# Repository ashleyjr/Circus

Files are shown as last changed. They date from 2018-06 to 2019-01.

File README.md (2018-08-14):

# Circus

## Installs

### Python 2.7
#### pip           
$ sudo apt-get install python-pip python-dev build-essential      

$ sudo pip install --upgrade pip 

$ sudo pip install --upgrade virtualenv 

$ sudo apt-get install python-tk    

### matplotlib     
$ sudo pip install matplotlib

### 8051
SDCC

SimplicityStudio

### Schematic capture/layout
#### KiCad
$sudo add-apt-repository --yes ppa:js-reynaud/kicad-4

$sudo apt update

$sudo apt install kicad

### Docs
$ sudo apt-get install texlive-latex-base

$ sudo apt-get install texlive-latex-extra

### GUI
$ sudo apt-get install libgtk-3-dev

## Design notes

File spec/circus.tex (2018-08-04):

\documentclass[a4paper]{article}

\usepackage{fullpage} % Package to use full page
\usepackage{parskip} % Package to tweak paragraph skipping
\usepackage{tikz} % Package for drawing
\usepackage{amsmath}
\usepackage{hyperref}

\title{Circus Specification}
\author{Ashley J. Robinson}
\date{\today}

\begin{document}

\maketitle

\section{Introduction}

   \subsection{Acronyms} 
      \begin{table}[h]
         \centering
         \caption{Acronyms}
         \label{tab_acronyms}
         \begin{tabular}{|l|l|}
            \hline
            \textbf{Acronyms}    &  \textbf{Description}                         \\ \hline  
            CMD                  &  Command                                      \\ \hline
            GUI                  &  Graphical User Interface                     \\ \hline
            ID                   &  Identity                                     \\ \hline
            IR                   &  Infra-Red                                    \\ \hline
            LED                  &  Light Emitting Diode                         \\ \hline
            OOK                  &  On-Off Keying                                \\ \hline
            PC                   &  Personal Computer                            \\ \hline
            PW                   &  Parity Word                                  \\ \hline
            UART                 &  Universal Asynchronous Receiver-Transmitter  \\ \hline  
            USB                  &  Universal Serial Bus                         \\ \hline
         \end{tabular}
\end{table}  

\section{Agent}

   \subsection{ID}
      \begin{itemize}
         \item Agents have hardware pin straps to configure IDs
         \item Agents have a valid ID range of 0x01 to 0xFE inclusive
         \item Agent ID = pin strap value + 1
      \end{itemize}
  
   \subsection{CMD}
      \begin{itemize}
         \item The list off \textbf{CMDs} is held in Table~\ref{tab_cmds}. 
      \end{itemize}
 
      \begin{table}[h]
         \centering
         \caption{Valid agent \textbf{CMDs}}
         \label{tab_cmds}
         \begin{tabular}{|l|l|l|l|l|l|}
               \hline
               \textbf{CMD}   &  \textbf{Control}     &  \textbf{Green LED}   &  \textbf{Red LED}  &  \textbf{Left Motor}  &  \textbf{Right Motor} \\ \hline  
               0x00           &                       &                       &                    &                       &  Off                  \\ \hline   
               0x01           &                       &                       &                    &                       &  Forward slow         \\ \hline   
               0x02           &                       &                       &                    &                       &  Forward              \\ \hline   
               0x03           &                       &                       &                    &                       &  Forward fast         \\ \hline   
               0x04           &                       &                       &                    &                       &  Reverse slow         \\ \hline   
               0x05           &                       &                       &                    &                       &  Reverse              \\ \hline   
               0x06           &                       &                       &                    &                       &  Reverse fast         \\ \hline   
               ...            &                       &                       &                    &                       &                       \\ \hline   
               0x10           &                       &                       &                    &  Off                  &                       \\ \hline   
               0x11           &                       &                       &                    &  Forward slow         &                       \\ \hline   
               0x12           &                       &                       &                    &  Forward              &                       \\ \hline   
               0x13           &                       &                       &                    &  Forward fast         &                       \\ \hline   
               0x14           &                       &                       &                    &  Reverse slow         &                       \\ \hline   
               0x15           &                       &                       &                    &  Reverse              &                       \\ \hline   
               0x16           &                       &                       &                    &  Reverse fast         &                       \\ \hline   
               ...            &                       &                       &                    &                       &                       \\ \hline   
               0x20           &                       &                       &  Force off         &                       &                       \\ \hline   
               0x21           &                       &                       &  Force on          &                       &                       \\ \hline   
               0x22           &                       &                       &  Low battery       &                       &                       \\ \hline   
               0x23           &                       &                       &  Full battery      &                       &                       \\ \hline   
               0x24           &                       &                       &  Blink on rx       &                       &                       \\ \hline   
               0x25           &                       &                       &  Blink on tx       &                       &                       \\ \hline   
               ...            &                       &                       &                    &                       &                       \\ \hline   
               0x30           &                       &  Force off            &                    &                       &                       \\ \hline   
               0x31           &                       &  Force on             &                    &                       &                       \\ \hline   
               0x32           &                       &  Low battery          &                    &                       &                       \\ \hline   
               0x33           &                       &  Full battery         &                    &                       &                       \\ \hline   
               0x34           &                       &  Blink on rx          &                    &                       &                       \\ \hline   
               0x35           &                       &  Blink on tx          &                    &                       &                       \\ \hline   
               ...            &                       &                       &                    &                       &                       \\ \hline   
               0x80           &  Shut down            &                       &                    &                       &                       \\ \hline   

         \end{tabular}
      \end{table}

\section{Communications}
 
\begin{itemize}
   \item The communication scheme overview is shown in Figure~\ref{fig_communications}. 
   \item Communication is achieved using and \textbf{IR} link.
   \item The carrier for the link is 38KHz.
   \item The carrier will be modulated with a \textbf{UART} using \textbf{OOK}.
   \item The \textbf{UART} baud rate will be 9600.
   \item The \textbf{UART} will carry 8 bits of data.
   \item The \textbf{UART} will 1 start/stop bit.
   \item The \textbf{UART} will not contain a parity bit.
   \item The \textbf{UART} will not use flow control.
\end{itemize}

\begin{figure}[h]
   \centering
   \label{fig_communications}
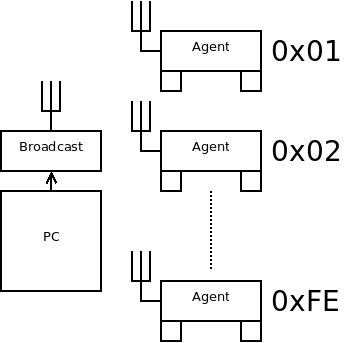
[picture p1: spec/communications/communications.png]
    
   \caption{Communication overview.}
\end{figure}

   \subsection{Broadcast}
      \begin{itemize}
         \item The IR receiver will be connected to UART transmitter of a microcontroller. 
         \item The \textbf{UART} signal will gate the carrier.
         \item The broadcaster will be connected to a \textbf{PC}.
         \item The \textbf{PC} will us a \textbf{GUI} application to control the broadcaster.
         \item The microcontroller used to control the broadcast will communicate
               with the \textbf{PC} using low speed \textbf{USB}.
      \end{itemize}

   \subsection{Receiver}
      \begin{itemize}
         \item The IR receiver will be connected to UART receiver of the microcontroller. 
         \item The receiver is initially in the \textbf{OFF} state. 
         \item The recover polls every 200ms for a carrier.
         \item The receiver must successfully find a carrier in two adjacent polls to switch the 
               receiver in to the \textbf{ON} state.
         \item Once in the \textbf{ON} state the receiver will constantly monitor the presence 
               of a carrier and return to the `\textbf{OFF} state when the carrier is lost. 
               This is 
      \end{itemize}

      \begin{figure}[h]
         \centering
         \label{fig_communications_time}
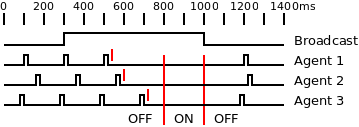
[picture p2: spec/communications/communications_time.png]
          
         \caption{Communication initiate timeout.}
      \end{figure}

\begin{itemize}
   \item    The agent receiver state machine is shown in Figure~\ref{fig_communications_sm}.
   \item    0xFF is invalid in both the \textbf{ID} and \textbf{CMD} states and will 
            push the state back to idle \textbf{ID} state. This can be used to reset the state machine
            as flushing with 0xFF will have no action.
   \item    Unmatching IDs will be stalled to allow \textbf{CMD} and \textbf{PW} to pass which may clash with valid \textbf{IDs}. 
   \item    Valid agents are shown in Table~\ref{tab_ids}.
   \item    Upon leaving the \textbf{ID} state an action must be reached before 50ms.
            An example of a completed and timed out transaction is shown in Figure~\ref{fig_communications_wave}.
   \item    The 
\end{itemize}

\begin{figure}[h]
   \centering
   \label{fig_communications_sm}
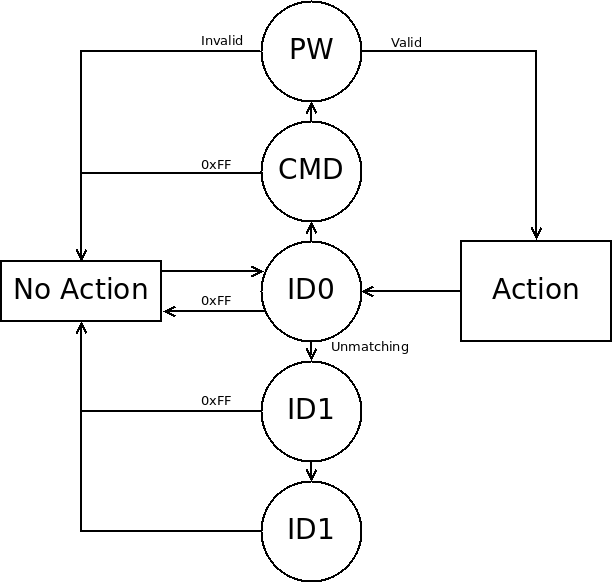
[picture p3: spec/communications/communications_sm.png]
    
   \caption{Communication state machine.}
\end{figure}

\begin{figure}[h]
   \centering
   \label{fig_communications_wave}
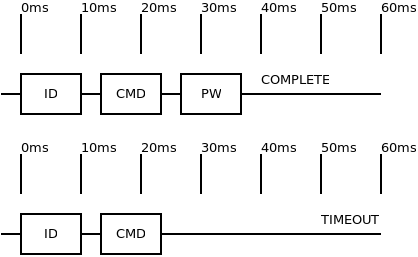
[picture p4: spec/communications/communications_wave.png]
    
   \caption{Communication message timeout.}
\end{figure}

\begin{table}[h]
   \centering
   \caption{Valid agent IDs.}
   \label{tab_ids}
   \begin{tabular}{|l|l|l|l|l|l|}
        \hline
        \textbf{ID}  &  \textbf{Description} \\ \hline  
         0x00        &  Issue the following command to all agents.\\ \hline  
         0x01..0xFE  &  Issue the following command to all agents with matching IDs.\\ \hline  
         0xFF        &  Resets the agent receiver state machine. \\ \hline  
   \end{tabular}
\end{table}

\section{GUI}
   \begin{itemize}
      \item The \textbf{GUI} will contain a tick box for every valid agent \textbf{ID}. 
      \item The \textbf{GUI} will contain a broadcast tick box which will disable all \textbf{ID}
            tick boxes.
      \item The \textbf{GUI} will contain a button to force a reset. 
      \item The arrow keys will be mapped to the directional control of the agents.
      \item The G key will be mapped to cycle through the green \textbf{LED}.
      \item The R key will be mapped to cycle thorugh the red \textbf{LED}
      \item The \textbf{GUI} will contain a text box streaming raw \textbf{CMDs} being set to the agents.
   \end{itemize}

\end{document}

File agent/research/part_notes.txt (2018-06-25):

25/06/18
   
   - Ordered coreless dc motor off eBay
      - https://www.ebay.co.uk/itm/5Pcs-DC-4-2V-46500RPM-6x14mm-Magnetic-Mini-Coreless-Motor-for-DIY-RC-Air-craft-U/202333907933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 
      - 5Pcs DC 4.2V 46500RPM 6x14mm Magnetic Mini Coreless Motor for DIY RC Air craft_U

   - Ordered 2 supercaps off eBay
      - https://www.ebay.co.uk/itm/112883887084
      - 2pcs 5.5V/4.0F Super Capacitor Double layer H Types Buttons Smart Capacitance ZY

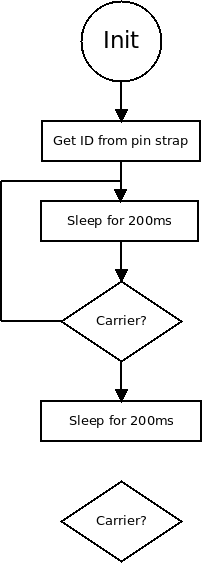
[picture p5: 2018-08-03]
spec/agent/agent_sm.png

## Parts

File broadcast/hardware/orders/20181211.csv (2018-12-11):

Line No. | Order Code | RoHS Compliant? | Your Part No | Notes | Qty | Manufacturer Part Number | Manufacturer Name | Manufacturer / Description | Availability | Unit Price | Line Price | Discount Price
3 | 1668592 | YES |  |  | 1.0 | TSW-112-07-G-S | SAMTEC | SAMTEC Board-To-Board Connector, Single, 2.54 mm, 12 Contacts, Header, TSW Series, Through Hole, 1 Rows | 42 | 1.0800 | 1.08
4 | 2495171 | YES |  |  | 10.0 | 885012206052 | WURTH ELEKTRONIK | WURTH ELEKTRONIK SMD Multilayer Ceramic Capacitor, 1 µF, 16 V, 0603 [1608 Metric], ± 10%, X7R, WCAP-CSGP Series | 65571 | 0.0909 | 0.91
5 | 2522395 | YES |  |  | 10.0 | C0603C104Z4VACTU | KEMET | KEMET SMD Multilayer Ceramic Capacitor, 0.1 µF, 16 V, 0603 [1608 Metric], +80%, -20%, Y5V, C Series KEMET | 7949 | 0.0434 | 0.43
6 | 1045518 | YES |  |  | 10.0 | TSUS4300 | VISHAY | VISHAY Infrared Emitter, 16 °, T-1 (3mm), 100 mA, 1.3 V, 800 ns, 800 ns | 13875 | 0.3410 | 3.41
7 | 2290360 | YES |  |  | 5.0 | KPA-1606CGCK | KINGBRIGHT | KINGBRIGHT LED, Side Look, Green, SMD, 20 mA, 2.1 V, 570 nm | 14381 | 0.1010 | 0.51
8 | 2290355 | YES |  |  | 5.0 | KPA-1606EC | KINGBRIGHT | KINGBRIGHT LED, Side Look, Red, SMD, 20 mA, 2 V, 617 nm | 2818 | 0.1070 | 0.54
9 | 1650675 | YES |  |  | 2.0 | 2238 | KEYSTONE | KEYSTONE Battery Strap, PP3 (9V) x 1, Rigid, Wire Leaded | 3962 | 0.7210 | 1.44
10 | 1018880 | NA |  |  | 1.0 | 6F22REL/1BP | PANASONIC | PANASONIC Battery, 9 V, PP3, Zinc Carbon, Snap Contact | 345 | 1.5900 | 1.59
11 | 1864517 | YES |  |  | 5.0 | IRLML6244TRPBF | INFINEON | INFINEON MOSFET Transistor, N Channel, 6.3 A, 20 V, 0.021 ohm, 4.5 V, 900 mV | 45339 | 0.2310 | 1.16
12 | 2324250 | YES |  |  | 10.0 | ERJ2GEJ113X | PANASONIC | PANASONIC SMD Chip Resistor, 0402 [1005 Metric], 11 kohm, ERJ2G Series, 50 V, Thick Film, 100 mW | 13470 | 0.0133 | 0.13
13 | 2447118 | Y-EX |  |  | 10.0 | MCWR04X1802FTL | MULTICOMP | MULTICOMP SMD Chip Resistor, 0402 [1005 Metric], 18 kohm, MCWR Series, 50 V, Thick Film, 62.5 mW | 2295 | 0.0040 | 0.04
14 | 2072929 | Y-EX |  |  | 10.0 | MCMR04X3302FTL | MULTICOMP | MULTICOMP SMD Chip Resistor, Ceramic, 0402 [1005 Metric], 33 kohm, MCMR Series, 50 V, Thick Film, 62.5 mW | 5500 | 0.0083 | 0.08
15 | 2447142 | Y-EX |  |  | 10.0 | MCWR04X24R0FTL | MULTICOMP | MULTICOMP SMD Chip Resistor, 0402 [1005 Metric], 24 ohm, MCWR Series, 50 V, Thick Film, 62.5 mW | 7870 | 0.0041 | 0.04
16 | 2302638 | YES |  |  | 10.0 | ERJ2RKF1001X | PANASONIC | PANASONIC SMD Chip Resistor, 0402 [1005 Metric], 1 kohm, ERJ2R Series, 50 V, Thick Film, 100 mW | 164822 | 0.0259 | 0.26
17 | 2140635 | Y-EX |  |  | 10.0 | CRCW040243R0FKED. | VISHAY | VISHAY SMD Chip Resistor, 0402 [1005 Metric], 43 ohm, CRCW Series, 50 V, Thick Film, 63 mW | 1508 | 0.0339 | 0.34
18 | 2447214 | Y-EX |  |  | 10.0 | MCWR04X7500FTL | MULTICOMP | MULTICOMP SMD Chip Resistor, 0402 [1005 Metric], 750 ohm, MCWR Series, 50 V, Thick Film, 62.5 mW | 14737 | 0.0041 | 0.04
19 | 2447144 | Y-EX |  |  | 10.0 | MCWR04X2700FTL | MULTICOMP | MULTICOMP SMD Chip Resistor, 0402 [1005 Metric], 270 ohm, MCWR Series, 50 V, Thick Film, 62.5 mW | 7730 | 0.0041 | 0.04
20 | 2140631 | Y-EX |  |  | 10.0 | CRCW040239R0FKED. | VISHAY | VISHAY SMD Chip Resistor, 0402 [1005 Metric], 39 ohm, CRCW Series, 50 V, Thick Film, 63 mW | 2831 | 0.0210 | 0.21
21 | 2112605 | YES |  |  | 10.0 | LM317DCY | TEXAS INSTRUMENTS | TEXAS INSTRUMENTS Linear Voltage Regulator, Adjustable, 40V primary input, 1.25V to 37V/1.5A/1 Output, SOT-223-4 | 9091 | 0.5630 | 5.63
22 | 2400948 | YES |  |  | 4.0 | C8051F850-C-GU | SILICON LABS | SILICON LABS 8 Bit MCU, High Speed CIP-51, C8051 Family C8051F85x Series Microcontrollers, 25 MHz, 8 KB | 343 | 0.8320 | 3.33
23 | 1593412 | YES |  |  | 100.0 | 2211S-03G | MULTICOMP | MULTICOMP Board-To-Board Connector, Vertical, 2.54 mm, 3 Contacts, Header, 2211S Series, Through Hole, 1 Rows | 261534 | 0.0147 | 1.47
 |  |  |  |  |  |  | Sub Total | 32.52
 |  |  |  |  |  |  | Goods Total | 32.52
 |  |  |  |  |  |  | Delivery | 0.00
 |  |  |  |  |  |  | VAT | Unknown

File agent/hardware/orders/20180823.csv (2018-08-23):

Line No. | Order Code | RoHS Compliant? | Your Part No | Notes | Qty | Manufacturer Part Number | Manufacturer Name | Manufacturer / Description | Availability | Unit Price | Line Price | Discount Price
1 | 2426954 | YES |  |  | 10.0 | GRM155R70G105KA12D | MURATA | MURATA SMD Multilayer Ceramic Capacitor, 0402 [1005 Metric], 1 µF, 4 V, ± 10%, X7R, GRM Series | Out of Stock | 0.1340 | 1.34
2 | 1572610 | YES |  |  | 10.0 | C0402C224K9PACTU | KEMET | KEMET SMD Multilayer Ceramic Capacitor, 0402 [1005 Metric], 0.22 µF, 6.3 V, ± 10%, X5R, C Series Kemet | 8006 | 0.0748 | 0.75
3 | 2852352 | YES |  |  | 10.0 | C0402C104K4RECAUTO | KEMET | KEMET SMD Multilayer Ceramic Capacitor, 0402 [1005 Metric], 0.1 µF, 16 V, ± 10%, X7R, C Series Kemet | 7988 | 0.0695 | 0.70
4 | 2290355 | YES |  |  | 5.0 | KPA-1606EC | KINGBRIGHT | KINGBRIGHT LED, Side Look, Red, SMD, 20 mA, 2 V, 617 nm | Out of Stock | 0.1070 | 0.54
5 | 2290360 | YES |  |  | 5.0 | KPA-1606CGCK | KINGBRIGHT | KINGBRIGHT LED, Side Look, Green, SMD, 20 mA, 2.1 V, 570 nm | 13561 | 0.1010 | 0.51
6 | 1593412 | YES |  |  | 50.0 | 2211S-03G | MULTICOMP | MULTICOMP Board-To-Board Connector, Vertical, 2.54 mm, 3 Contacts, Header, 2211S Series, Through Hole, 1 Rows | 103846 | 0.0144 | 0.72
7 | 2498581 | YES |  |  | 25.0 | PMV65XPEA | NEXPERIA | NEXPERIA MOSFET Transistor, P Channel, -2.8 A, -20 V, 0.067 ohm, -4.5 V, -1 V | 7324 | 0.1700 | 4.25
8 | 1653622 | YES |  |  | 15.0 | MMBT2222LT1G. | ON SEMICONDUCTOR | ON SEMICONDUCTOR Bipolar (BJT) Single Transistor, General Purpose, NPN, 30 V, 250 MHz, 225 mW, 600 mA, 250 hFE | 4191 Available until stock is exhausted | 0.0817 | 1.23
9 | 1864517 | YES |  |  | 15.0 | IRLML6244TRPBF | INFINEON | INFINEON MOSFET Transistor, N Channel, 6.3 A, 20 V, 21 mohm, 4.5 V, 0.9 V | 59117 | 0.2590 | 3.89
10 | 2072575 | Y-EX |  |  | 10.0 | MCMR04X1200FTL | MULTICOMP | MULTICOMP SMD Chip Resistor, Ceramic, 120 ohm, MCMR Series, 50 V, Thick Film, 0402 [1005 Metric], 62.5 mW | 21710 | 0.0081 | 0.08
11 | 2447096 | Y-EX |  |  | 100.0 | MCWR04X1002FTL | MULTICOMP | MULTICOMP SMD Chip Resistor, 10 kohm, MCWR Series, 50 V, Thick Film, 0402 [1005 Metric], 62.5 mW | 10380 | 0.0024 | 0.24
12 | 2072515 | Y-EX |  |  | 10.0 | MCMR04X1000FTL | MULTICOMP | MULTICOMP SMD Chip Resistor, Ceramic, 100 ohm, MCMR Series, 50 V, Thick Film, 0402 [1005 Metric], 62.5 mW | 6678 | 0.0081 | 0.08
13 | 2447135 | Y-EX |  |  | 100.0 | MCWR04X2203FTL | MULTICOMP | MULTICOMP SMD Chip Resistor, 220 kohm, MCWR Series, 50 V, Thick Film, 0402 [1005 Metric], 62.5 mW | 10048 | 0.0024 | 0.24
14 | 2447159 | Y-EX |  |  | 10.0 | MCWR04X3300FTL | MULTICOMP | MULTICOMP SMD Chip Resistor, 330 ohm, MCWR Series, 50 V, Thick Film, 0402 [1005 Metric], 62.5 mW | 17370 | 0.0040 | 0.04
15 | 2059190 | YES |  |  | 20.0 | ERJ2GE0R00X | PANASONIC ELECTRONIC COMPONENTS | PANASONIC ELECTRONIC COMPONENTS SMD Chip Resistor, 0 ohm, ERJ2G Series, 50 V, Thick Film, 0402 [1005 Metric], 100 mW | 337069 | 0.0159 | 0.32
16 | 2302479 | YES |  |  | 10.0 | ERJ2RKF39R0X | PANASONIC ELECTRONIC COMPONENTS | PANASONIC ELECTRONIC COMPONENTS SMD Chip Resistor, 39 ohm, ERJ2R Series, 50 V, Thick Film, 0402 [1005 Metric], 100 mW | 11497 | 0.0216 | 0.22
17 | 1652785 | YES |  |  | 10.0 | CRCW040233R0FKED | VISHAY | VISHAY SMD Chip Resistor, 33 ohm, CRCW Series, 50 V, Thick Film, 0402 [1005 Metric], 63 mW | 7498 | 0.0260 | 0.26
18 | 2072516 | Y-EX |  |  | 30.0 | MCMR04X1001FTL | MULTICOMP | MULTICOMP SMD Chip Resistor, Ceramic, 1 kohm, MCMR Series, 50 V, Thick Film, 0402 [1005 Metric], 63 mW | Out of Stock | 0.0081 | 0.24
19 | 2251364 | YES |  |  | 5.0 | TSOP38438 | VISHAY | VISHAY Infrared Receiver, Remote Control, 38 kHz, 45m, 45 °, 5.5 V, 2.5 V, -25 °C | 733 | 0.5720 | 2.86
20 | 2492300 | YES |  |  | 3.0 | LP3985IM5-2.7/NOPB | TEXAS INSTRUMENTS | TEXAS INSTRUMENTS Fixed LDO Voltage Regulator, 2.5V to 6V, 60mV Dropout, 2.7Vout, 150mAout, SOT-23-5 | 834 | 0.5020 | 1.51
21 | 2400948 | YES |  |  | 3.0 | C8051F850-C-GU | SILICON LABS | SILICON LABS 8 Bit Microcontroller, High Speed CIP-51, C8051 Family C8051F85x Series Microcontrollers, 25 MHz | 370 | 0.8230 | 2.47
 |  |  |  |  |  |  | Sub Total | 22.46
 |  |  |  |  |  |  | Goods Total | 22.46
 |  |  |  |  |  |  | Delivery | 0.00
 |  |  |  |  |  |  | VAT | Unknown
 |  |  |  |  |  |  | Total | 22.46

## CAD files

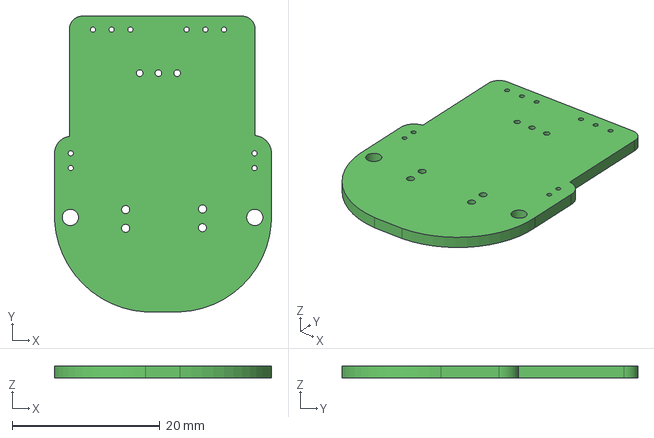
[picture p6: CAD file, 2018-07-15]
agent/hardware/model/circus_agent.step
29.4 x 40.1 x 1.60 mm

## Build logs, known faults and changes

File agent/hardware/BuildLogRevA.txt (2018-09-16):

   - The holes for the motor wire are way too big
   - The holes for the 3-way debug headers are too small and won't takw the compoent
   - When powering off the programmer it fails when the H bridge is populated
   - Need a silkscreen box to wrote the ID on
   - Replace the debug header with some polarised pads so pogo pins can be added

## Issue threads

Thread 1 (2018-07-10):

3D Model agent

ashleyjr, 2018-07-10:
- PCB
- Motors
- Charging

ashleyjr, 2018-07-22:
Exported PCB.
 - CAD motors
 - CAD super cap

ashleyjr, 2018-08-14:
Have fab parts now so any need to?

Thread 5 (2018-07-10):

SDCC working

ashleyjr, 2018-07-10:
Getting complier and toolchain working with dev board

Read ADC and send over should do it

ashleyjr, 2018-08-14:
Working fine

Closed 2018-08-14.

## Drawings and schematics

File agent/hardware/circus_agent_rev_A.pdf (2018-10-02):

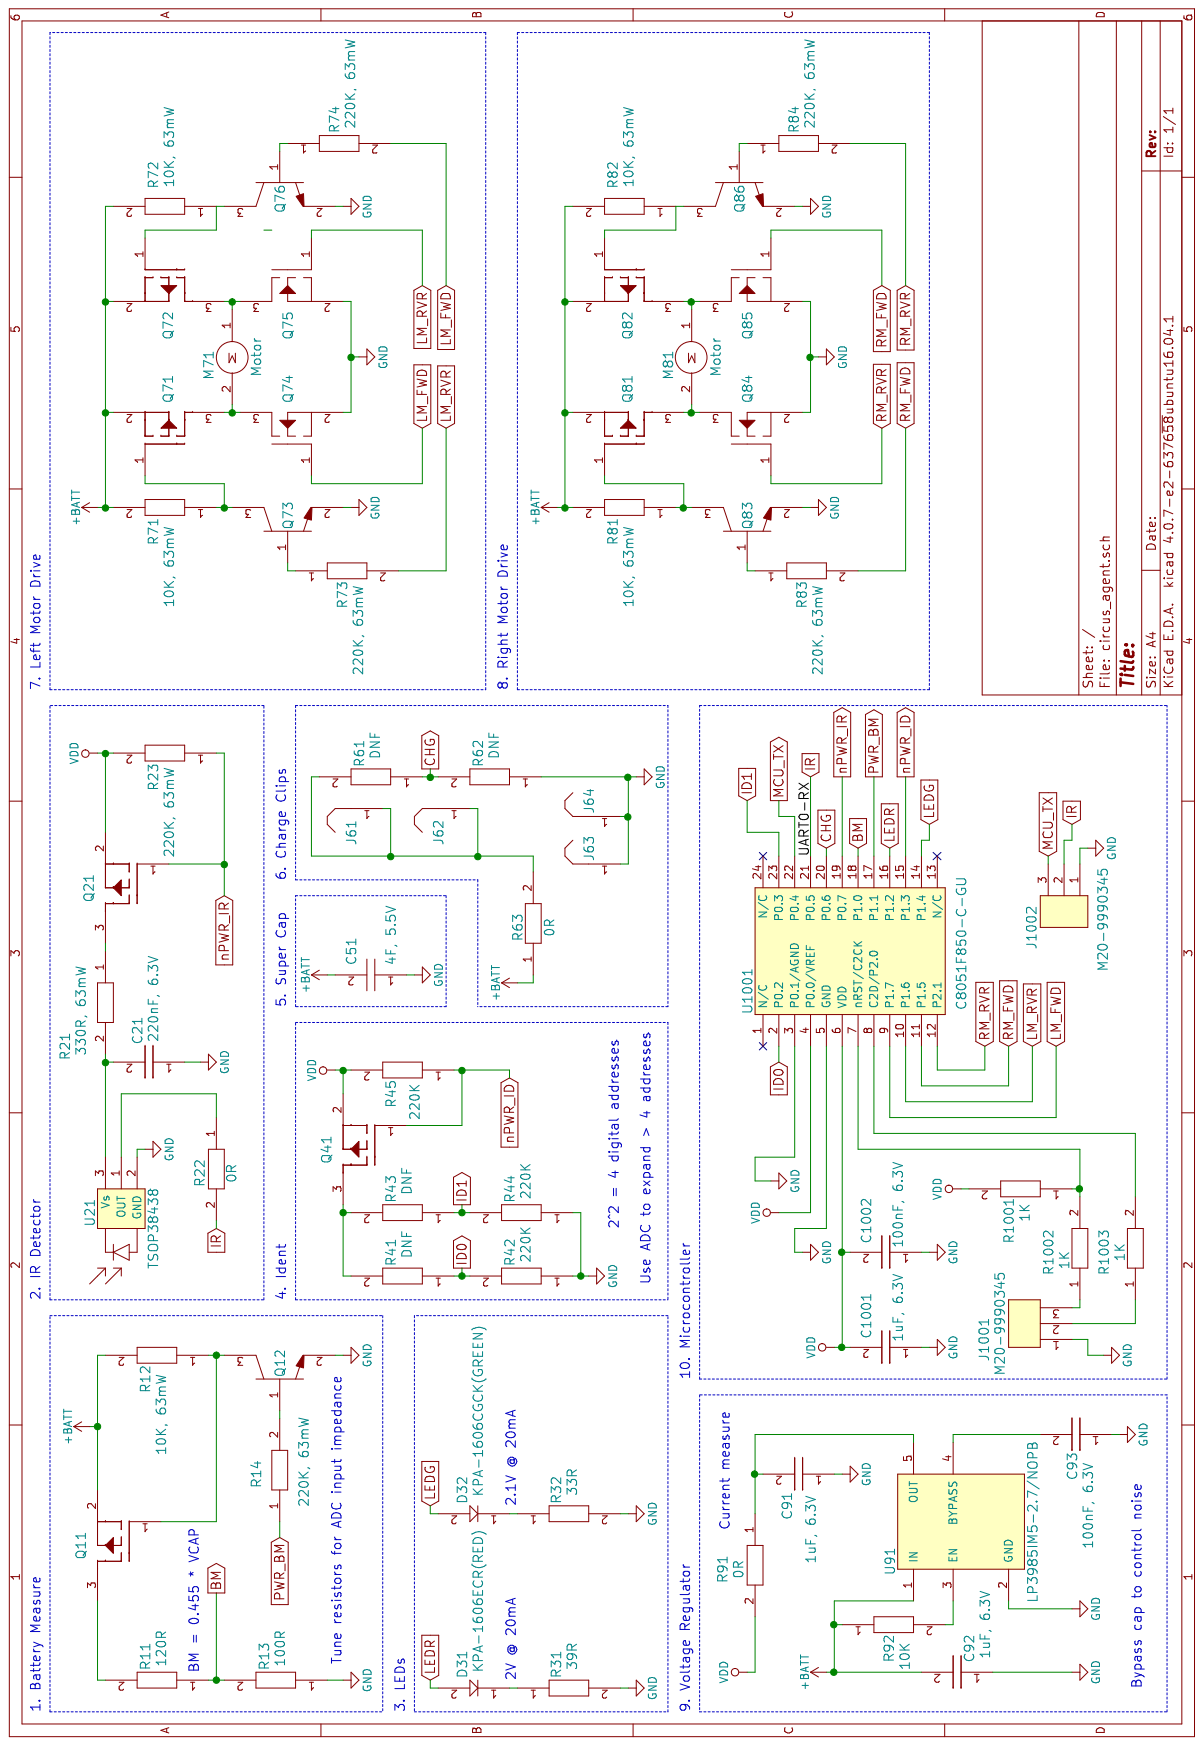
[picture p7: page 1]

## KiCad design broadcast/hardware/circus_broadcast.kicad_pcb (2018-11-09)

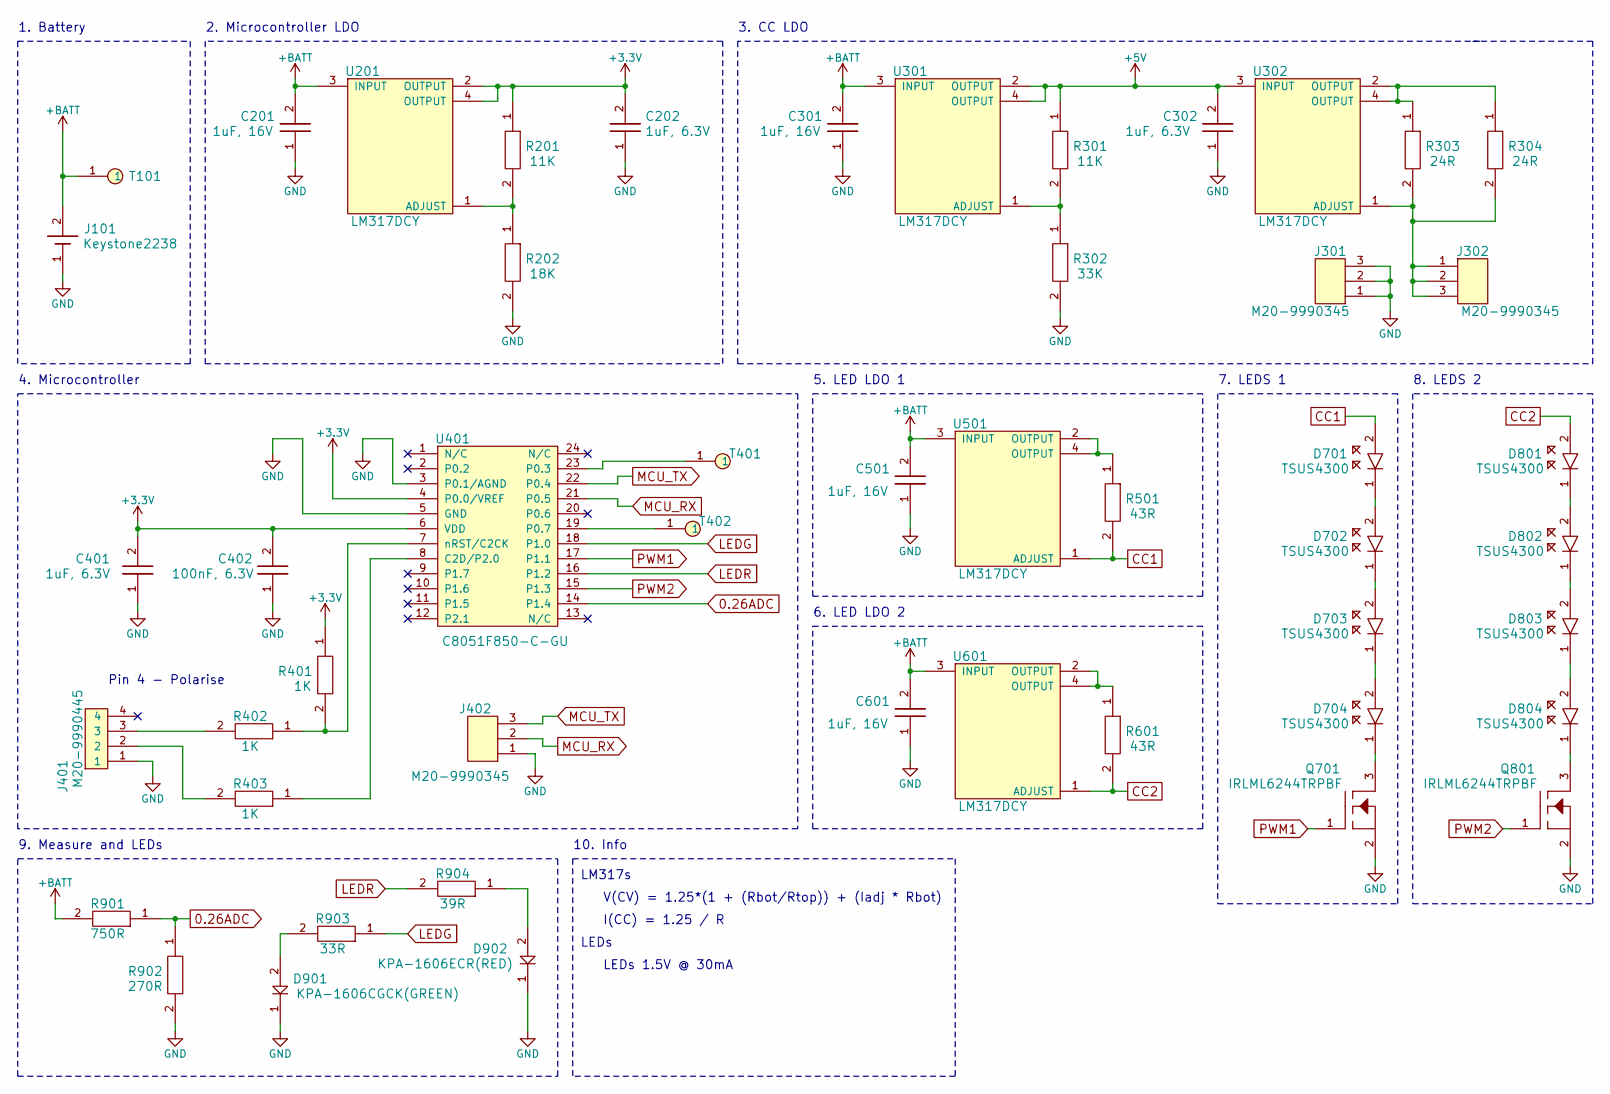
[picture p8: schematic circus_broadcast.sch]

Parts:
C201, C301, C501, C601: 1uF, 16V; 0603
C202, C302, C401: 1uF, 6.3V; 0603
C402: 100nF, 6.3V; 0402
D701, D702, D703, D704, D801, D802, D803, D804: TSUS4300
D901: KPA-1606CGCK(GREEN); KPA
D902: KPA-1606ECR(RED); KPA
J101: Keystone2238
J301, J302, J402: M20-9990345
J401: M20-9990445
Q701, Q801: IRLML6244TRPBF
R201, R301: 11K; 0402
R202: 18K; 0402
R302: 33K; 0402
R303, R304: 24R; 0402
R401, R402, R403: 1K; 0402
R501, R601: 43R; 0402
R901: 750R; 0402
R902: 270R; 0402
R903: 33R; 0402
R904: 39R; 0402
T101, T401, T402: TestPoint
U201, U301, U302, U501, U601: LM317DCY
U401: C8051F850-C-GU

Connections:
0.26ADC: R901.1, R902.1, U401.14 (P1.4)
+3V3: C202.2, C401.2, C402.2, R201.1, R401.1, U201.2 (OUTPUT), U201.4 (OUTPUT), U401.4 (P0.0/VREF), U401.6 (VDD)
+5V: C302.2, R301.1, U301.2 (OUTPUT), U301.4 (OUTPUT), U302.3 (INPUT)
+BATT: C201.2, C301.2, C501.2, C601.2, J101.2, R901.2, T101.1, U201.3 (INPUT), U301.3 (INPUT), U501.3 (INPUT), U601.3 (INPUT)
CC1: D701.2, R501.2, U501.1 (ADJUST)
CC2: D801.2, R601.2, U601.1 (ADJUST)
GND: C201.1, C202.1, C301.1, C302.1, C401.1, C402.1, C501.1, C601.1, D901.1, D902.1, J101.1, J301.1, J301.2, J301.3, J401.1, J402.1, Q701.2, Q801.2, R202.2, R302.2, R902.2, U401.3 (P0.1/AGND), U401.5 (GND)
LEDG: R903.1, U401.18 (P1.0)
LEDR: R904.2, U401.16 (P1.2)
MCU_RX: J402.2, U401.21 (P0.5)
MCU_TX: J402.3, U401.22 (P0.4)
unnamed: D701.1, D702.2
unnamed: D702.1, D703.2
unnamed: D703.1, D704.2
unnamed: D704.1, Q701.3
unnamed: D801.1, D802.2
unnamed: D802.1, D803.2
unnamed: D803.1, D804.2
unnamed: D804.1, Q801.3
unnamed: D901.2, R903.2
unnamed: D902.2, R904.1
unnamed: J302.1, J302.2, J302.3, R303.2, R304.2, U302.1 (ADJUST)
unnamed: J401.2, R403.2
unnamed: J401.3, R402.2
unnamed: R201.2, R202.1, U201.1 (ADJUST)
unnamed: R301.2, R302.1, U301.1 (ADJUST)
unnamed: R303.1, R304.1, U302.2 (OUTPUT), U302.4 (OUTPUT)
unnamed: R401.2, R402.1, U401.7 (nRST/C2CK)
unnamed: R403.1, U401.8 (C2D/P2.0)
unnamed: R501.1, U501.2 (OUTPUT), U501.4 (OUTPUT)
unnamed: R601.1, U601.2 (OUTPUT), U601.4 (OUTPUT)
unnamed: T401.1, U401.23 (P0.3)
unnamed: T402.1, U401.19 (P0.7)
PWM1: Q701.1, U401.17 (P1.1)
PWM2: Q801.1, U401.15 (P1.3)

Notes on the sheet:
Pin 4 - Polarise
1. Battery
2. Microcontroller LDO
3. CC LDO
4. Microcontroller
V(CV) = 1.25*(1 + (Rbot/Rtop)) + (Iadj * Rbot)
I(CC) = 1.25 / R
LEDs 1.5V @ 30mA
5. LED LDO 1
6. LED LDO 2
7. LEDS 1
8. LEDS 2
LM317s
LEDs
10. Info
9. Measure and LEDs

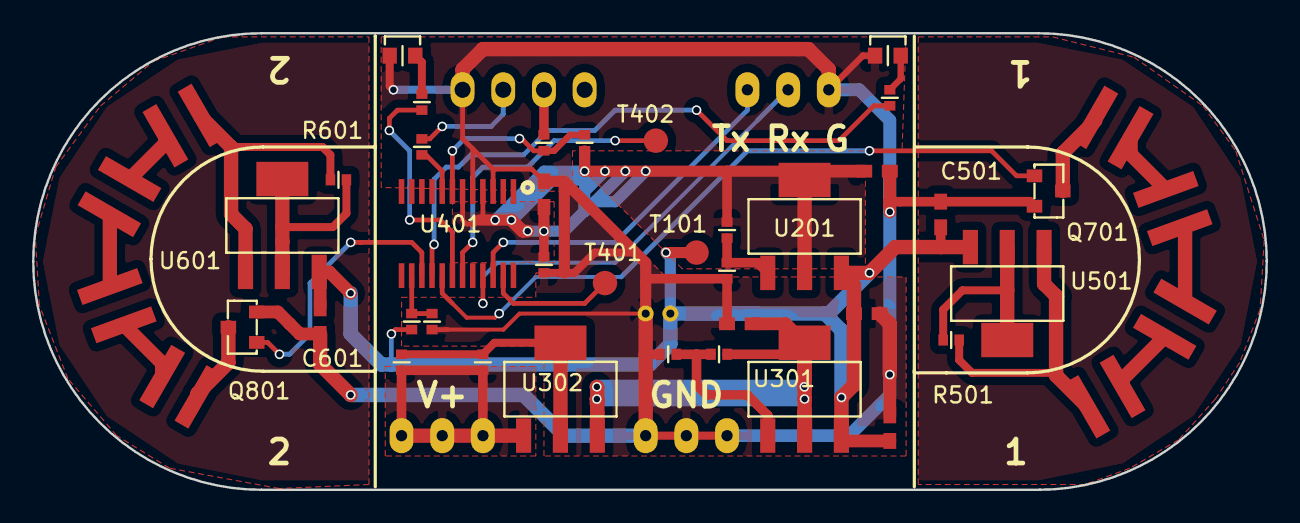
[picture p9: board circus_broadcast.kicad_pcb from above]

Board: 2 copper layers, 77.0 x 28.5 mm, 49 parts (0 on the bottom side), 35 nets.

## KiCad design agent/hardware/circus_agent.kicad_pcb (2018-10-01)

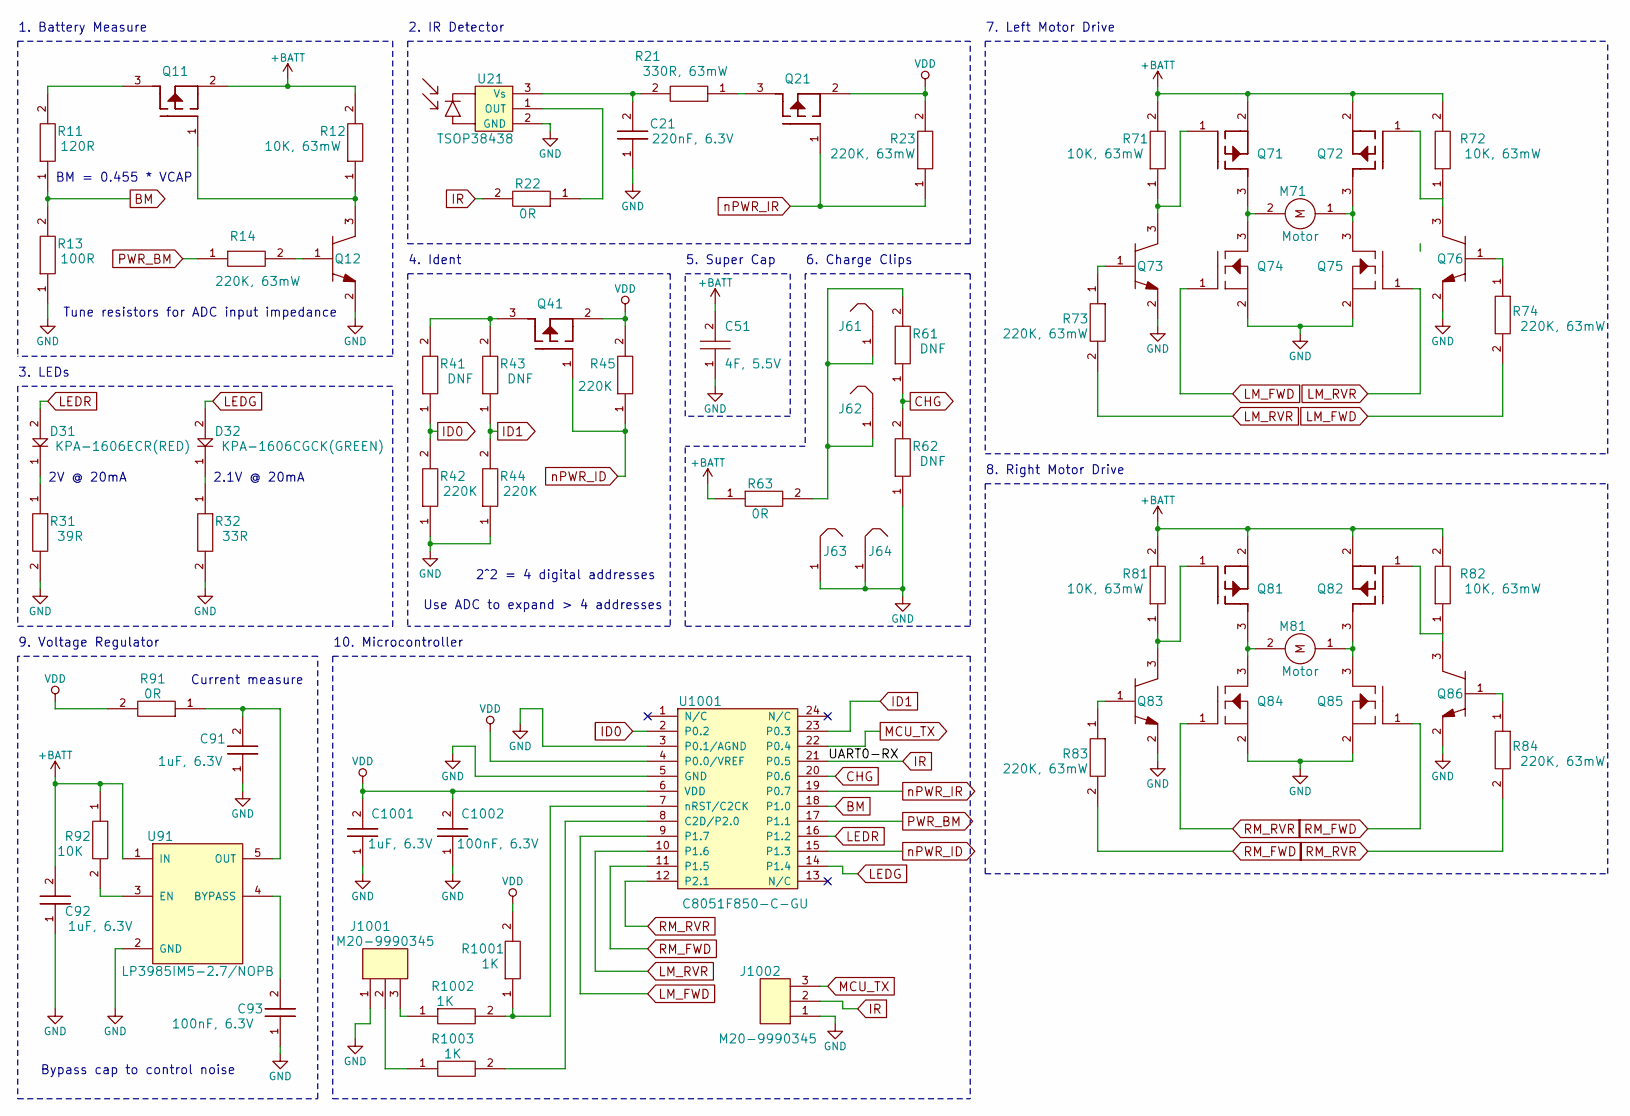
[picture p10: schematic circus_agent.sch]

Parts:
C21: 220nF, 6.3V; 0402; PartNum MC0402X224K6R3CT
C51: 4F, 5.5V; SuperCap
C91, C92, C1001: 1uF, 6.3V; 0402; PartNum MC0402X224K6R3CT
C93, C1002: 100nF, 6.3V; 0402; PartNum MC0402X224K6R3CT
D31: KPA-1606ECR(RED); KPA
D32: KPA-1606CGCK(GREEN); KPA
J61, J62, J63, J64: PowerClip
J1001, J1002: M20-9990345
M71, M81: Motor
Q11, Q21, Q41, Q71, Q72, Q81, Q82: PMV65XPEA; PartNum PMV65XPEA
Q12, Q73, Q76, Q83, Q86: MMBT2222LT1G
Q74, Q75, Q84, Q85: IRLML6244TRPBF
R11: 120R; 0402; PartNum MCMR04X4701FTL
R12, R71, R72, R81, R82: 10K, 63mW; 0402; PartNum MCMR04X4701FTL
R13: 100R; 0402; PartNum MCMR04X4701FTL
R14, R23, R73, R74, R83, R84: 220K, 63mW; 0402; PartNum MCMR04X4701FTL
R21: 330R, 63mW; 0402; PartNum CRCW0402330RFKED
R22, R63, R91: 0R; 0402; PartNum MCMR04X4701FTL
R31: 39R; 0402; PartNum MCMR04X4701FTL
R32: 33R; 0402; PartNum MCMR04X4701FTL
R41, R43, R61, R62: DNF; 0402; PartNum MCMR04X4701FTL
R42, R44, R45: 220K; 0402; PartNum MCMR04X4701FTL
R92: 10K; 0402; PartNum MCMR04X4701FTL
R1001, R1002, R1003: 1K; 0402; PartNum MCMR04X4701FTL
U21: TSOP38438
U91: LP3985IM5-2.7/NOPB; LP3985
U1001: C8051F850-C-GU

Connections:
+BATT: C51.2, C92.2, Q11.2, Q71.2, Q72.2, Q81.2, Q82.2, R12.2, R63.1, R71.2, R72.2, R81.2, R82.2, R92.1, U91.1 (IN)
BM: R11.1, R13.2, U1001.18 (P1.0)
CHG: R61.1, R62.2, U1001.20 (P0.6)
GND: C21.1, C51.1, C91.1, C92.1, C93.1, C1001.1, C1002.1, J63.1, J64.1, J1001.1, J1002.1, Q12.2, Q73.2, Q74.2, Q75.2, Q76.2, Q83.2, Q84.2, Q85.2, Q86.2, R13.1, R31.2, R32.2, R42.1, R44.1, R62.1, U21.2 (GND), U91.2 (GND), U1001.3 (P0.1/AGND), U1001.5 (GND)
ID0: R41.1, R42.2, U1001.2 (P0.2)
ID1: R43.1, R44.2, U1001.23 (P0.3)
IR: J1002.2, R22.2, U1001.21 (P0.5)
LEDG: D32.2, U1001.14 (P1.4)
LEDR: D31.2, U1001.16 (P1.2)
LM_FWD: Q74.1, R74.2, U1001.9 (P1.7)
LM_RVR: Q75.1, R73.2, U1001.10 (P1.6)
MCU_TX: J1002.3, U1001.22 (P0.4)
unnamed: C21.2, R21.2, U21.3 (Vs)
unnamed: C91.2, R91.1, U91.5 (OUT)
unnamed: C93.2, U91.4 (BYPASS)
unnamed: D31.1, R31.1
unnamed: D32.1, R32.1
unnamed: J61.1, J62.1, R61.2, R63.2
unnamed: J1001.2, R1003.1
unnamed: J1001.3, R1002.1
unnamed: M71.1, Q72.3, Q75.3
unnamed: M71.2, Q71.3, Q74.3
unnamed: M81.1, Q82.3, Q85.3
unnamed: M81.2, Q81.3, Q84.3
unnamed: Q11.1, Q12.3, R12.1
unnamed: Q11.3, R11.2
unnamed: Q12.1, R14.2
unnamed: Q21.3, R21.1
unnamed: Q41.3, R41.2, R43.2
unnamed: Q71.1, Q73.3, R71.1
unnamed: Q72.1, Q76.3, R72.1
unnamed: Q73.1, R73.1
unnamed: Q76.1, R74.1
unnamed: Q81.1, Q83.3, R81.1
unnamed: Q82.1, Q86.3, R82.1
unnamed: Q83.1, R83.1
unnamed: Q86.1, R84.1
unnamed: R22.1, U21.1 (OUT)
unnamed: R92.2, U91.3 (EN)
unnamed: R1001.1, R1002.2, U1001.7 (nRST/C2CK)
unnamed: R1003.2, U1001.8 (C2D/P2.0)
PWR_BM: R14.1, U1001.17 (P1.1)
RM_FWD: Q85.1, R83.2, U1001.11 (P1.5)
RM_RVR: Q84.1, R84.2, U1001.12 (P2.1)
VDD: C1001.2, C1002.2, Q21.2, Q41.2, R23.2, R45.2, R91.2, R1001.2, U1001.4 (P0.0/VREF), U1001.6 (VDD)
nPWR_ID: Q41.1, R45.1, U1001.15 (P1.3)
nPWR_IR: Q21.1, R23.1, U1001.19 (P0.7)

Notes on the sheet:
7. Left Motor Drive
8. Right Motor Drive
2. IR Detector
4. Ident
1. Battery Measure
10. Microcontroller
3. LEDs
5. Super Cap
2V @ 20mA
2.1V @ 20mA
9. Voltage Regulator
Bypass cap to control noise
2^2 = 4 digital addresses
Use ADC to expand > 4 addresses
Current measure
6. Charge Clips
BM = 0.455 * VCAP
Tune resistors for ADC input impedance

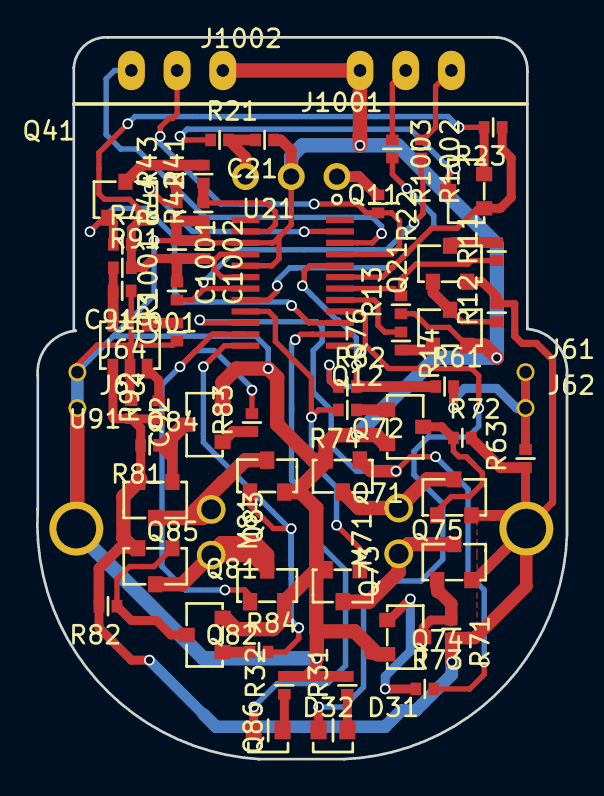
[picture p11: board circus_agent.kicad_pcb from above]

Board: 2 copper layers, 29.4 x 40.1 mm, 66 parts (1 on the bottom side), 47 nets.

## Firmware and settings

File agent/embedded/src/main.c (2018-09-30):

//-----------------------------------------------------------------------------
// Project: Circus/embedded
// File: 	main.c
// Brief:	Single main file containing all code
//-----------------------------------------------------------------------------

//-----------------------------------------------------------------------------
// Includes
//-----------------------------------------------------------------------------

#include "SI_C8051F850_Register_Enums.h"
#include "SI_C8051F850_Defs.h"

//-----------------------------------------------------------------------------
// Defines
//-----------------------------------------------------------------------------

#define SYSCLK      		24500000   				// SYSCLK frequency in Hz
#define BAUDRATE   		115200					// Baud rate of UART in bps
//
#define UART_SIZE_IN		8
#define UART_SIZE_OUT   20
#define ADC1				0x08
#define ADC2				0x09
#define ADC3				0x0A

SBIT(LED1, SFR_P1, 2);                       // P1.2 LED
SBIT(LED0, SFR_P1, 4);                 		// P1.4 LED

SBIT(RM, SFR_P1, 5);
SBIT(LM, SFR_P1, 6);

//-----------------------------------------------------------------------------
// Prototypes
//-----------------------------------------------------------------------------

void u32_to_dec_str(U32 data, U8 * ptr);
void u32_to_hex_str(U32 data, U8 * ptr);
void  setup(void);
U8    uartRx();
void  uartLoadIn(U8 rx);
void  uartLoadOut(U8 tx);
U8    uartSizeIn(void);
void  uartTransmit(void);
U16   readAdc(void);
void  motorControl(void);

//-----------------------------------------------------------------------------
// Global Variables
//-----------------------------------------------------------------------------

volatile U16   motor_pwm_counter;
volatile    U16   motor_duty_left;
volatile    U16   motor_duty_right;


volatile U8 	uart_in[UART_SIZE_IN];
volatile U8 	in_head;
volatile U8 	in_tail;
volatile U8 	uart_out[UART_SIZE_OUT];
volatile U8 	out_head;
volatile U8 	out_tail;

//-----------------------------------------------------------------------------
// Main Routine
//-----------------------------------------------------------------------------

#define PERIOD 10000
void main (void){ 
   volatile U8 data;
   U32 i;
   U8 str[32];
  
   SCON0_TI 	= 1; 
	SCON0_RI 	= 0;
  

   in_tail  = 0;
   in_head  = 0;
   out_tail = 0;
   out_head = 0;
   
   setup();

  
   motor_pwm_counter    = 0;
   motor_duty_left      = 0; 
   motor_duty_right     = 0; 
   
   
   setup();

	SCON0_TI 	= 1; 
	SCON0_RI 	= 0;
  
   LM = 0;
   RM = 0;
   
   LED0     = 1;
   LED1     = 1;
  
   while (1){ 
      if(SCON0_RI){   
         SCON0_RI = 0;
         data = SBUF0;
         
         uartLoadOut('\n');	
         uartLoadOut('\r');	
         uartLoadOut(data); 
         if('A' == data){
            if(motor_duty_right < 255){	
               motor_duty_right+=8;
            }
            u32_to_dec_str((U32)motor_duty_right, str);
         }
         if('B' == data){
            if(motor_duty_right != 0){
               motor_duty_right-=8;
            }
            u32_to_dec_str((U32)motor_duty_right, str);
         }
         if('C' == data){
            if(motor_duty_left < 255){
               motor_duty_left+=8;
            }
            u32_to_dec_str((U32)motor_duty_left, str);
         }
         if('D' == data){;
            if(motor_duty_left != 0){
               motor_duty_left-=8;
            }
            u32_to_dec_str((U32)motor_duty_left, str);
         }
         for(i=0;i<10;i++){
            uartLoadOut(str[i]);
         } 
      }
	}
} 

//-----------------------------------------------------------------------------
// Interrupt Routines
//-----------------------------------------------------------------------------

INTERRUPT (TIMER1_ISR, TIMER1_IRQn){}				// Needed for UART timing	

INTERRUPT (TIMER2_ISR, TIMER2_IRQn){			   // Timer running at 4KHz 
   uartTransmit();  
   motor_pwm_counter++;
   if(motor_pwm_counter == 255){
      motor_pwm_counter = 0;
   } 
   if(0 == motor_pwm_counter){
      LM = 1;
      RM = 1;
   }
   if(motor_duty_left < motor_pwm_counter){ 
      LM = 0;
   }
   if(motor_duty_right < motor_pwm_counter){ 
      RM = 0;
   }
   TMR2H = 255;                                 // Reset timer
   TMR2CN_TF2H = 0; 
}

//-----------------------------------------------------------------------------
// Routines
//-----------------------------------------------------------------------------



// Turn 32 bit data in to a string of 10 chars
void u32_to_dec_str(U32 data, U8 * ptr){
   U8 * p;
   S8 i,j;
   U32 c, d, m;
   d = data;
   p = ptr;
   for(i=9;i>-1;i--){ 
      m = 1;
      for(j=0;j<i;j++){
         m *= 10;
      }
      c = d / m; 
      *p = (U8)c + 48;
      *p++;
      d -= c * m;
   }
}

// Turn 32 bit data In to a string of 8 chars
void u32_to_hex_str(U32 data, U8 * ptr){
   U8 * p;
   S8 i;
   U32 c, d;
   d = data;
   p = ptr;
   for(i=28;i>-1;i-=4){
      c = d >> i; 
      if(c > 9){
         *p = c + 55;
      }else{
         *p = c + 48;
      }
      *p++;
      d -= c << i;
   }
}

U8 uartRx(){
   U8 data = 0;
   if(in_head != in_tail){
      data = uart_in[in_tail];                   // Timer tuned so no need to check
      in_tail++;                                   // Transmit UART
      in_tail %= UART_SIZE_IN;                    // Wrap around
   }
   return data;
}

void uartLoadIn(U8 rx){
   uart_in[in_head] = rx;
   in_head++;
   in_head %= UART_SIZE_IN;
}

U8 uartSizeIn(void){
   if(in_head < in_tail){
      return UART_SIZE_IN - in_tail + in_head;
   }else{
      return in_head - in_tail;
   }
}

void uartLoadOut(U8 tx){			               // Handle buffering out Tx UART
	uart_out[out_head] = tx;	                  // Buffer outgoing						
	out_head++;
   out_head %= UART_SIZE_OUT;			            // Wrap around
}

void uartTransmit(void){
   if(out_head != out_tail){
      SBUF0 = uart_out[out_tail];                   // Timer tuned so no need to check
      out_tail++;                                   // Transmit UART
      out_tail %= UART_SIZE_OUT;                    // Wrap around
   }
}

U16 readAdc(void){                              // Read the available ADCs
   U8 i;
   ADC0MX = ADC3;
   for(i=0;i<2;i++){
      ADC0CN0 |= ADC0CN0_ADBUSY__SET;
      while(ADC0CN0 & ADC0CN0_ADBUSY__SET);     // Wait for sample to complete
   }
   return (U16)ADC0;        
}


void setup(void){ 
	U8 TCON_save;
	// Watchdog 
		WDTCN = 0xDE; 								      // First key
		WDTCN = 0xAD; 								      // Second key - Watchdog now disabled
	// Clock
		CLKSEL = 
			CLKSEL_CLKSL__HFOSC 				| 	      // Use 24.5MHz interal clock
			CLKSEL_CLKDIV__SYSCLK_DIV_1;			   // Do not divide
	// Port 0
		P0MDOUT = 
			P0MDOUT_B0__PUSH_PULL 				| 	// PWM1 output
			P0MDOUT_B1__PUSH_PULL 				| 	// PWM2 output
			P0MDOUT_B2__OPEN_DRAIN				| 
			P0MDOUT_B3__OPEN_DRAIN 				| 
			P0MDOUT_B4__PUSH_PULL 				| 	   // UART TX
			P0MDOUT_B5__OPEN_DRAIN				| 	   // UART RX
			P0MDOUT_B6__OPEN_DRAIN 				| 
			P0MDOUT_B7__OPEN_DRAIN;
	// Port 1
		P1MDOUT = 
			P1MDOUT_B0__PUSH_PULL 				| 
			P1MDOUT_B1__OPEN_DRAIN 				| 
			P1MDOUT_B2__PUSH_PULL				| 
			P1MDOUT_B3__PUSH_PULL 				| 	// TEST2
			P1MDOUT_B4__PUSH_PULL 				| 	// TEST1
			P1MDOUT_B5__PUSH_PULL				|  // RM_FWD
			P1MDOUT_B6__PUSH_PULL 				|  // LM_RVR
			P1MDOUT_B7__PUSH_PULL;              // LM_FWD
		P1MDIN = 
			P1MDIN_B0__DIGITAL 					|	// ADC1
			P1MDIN_B1__DIGITAL 					| 	// ADC2
			P1MDIN_B2__DIGITAL					   | 	// ADC3
			P1MDIN_B3__DIGITAL 					| 
			P1MDIN_B4__DIGITAL 					| 
			P1MDIN_B5__DIGITAL					| 
			P1MDIN_B6__DIGITAL 					| 
			P1MDIN_B7__DIGITAL;
	// Port 2
		P2MDOUT = 
			P2MDOUT_B0__PUSH_PULL 				| 
			P2MDOUT_B1__PUSH_PULL;             // RM_RVR  	
   // Port crossbar
		XBR0 = 
			XBR0_URT0E__ENABLED 				   | 	// Route out UART
			XBR0_SPI0E__DISABLED 				| 
			XBR0_SMB0E__DISABLED				   | 
			XBR0_CP0E__DISABLED 				   | 
			XBR0_CP0AE__DISABLED 				| 
			XBR0_CP1E__DISABLED					| 
			XBR0_CP1AE__DISABLED 				|
			XBR0_SYSCKE__DISABLED;
		XBR1 = 
			XBR1_PCA0ME__CEX0_CEX1 				| 	// Route out PCA0 and PCA1
			XBR1_ECIE__DISABLED 				   | 
			XBR1_T0E__DISABLED					| 
			XBR1_T1E__DISABLED 					|
			XBR1_T2E__DISABLED;
		XBR2 = 
			XBR2_WEAKPUD__PULL_UPS_ENABLED 	| 	   // Weak pull ups
			XBR2_XBARE__ENABLED;					      // Enable cross bar
	// ADC
		//ADC0MX = 									// Mux set in application
		//	ADC0MX_ADC0MX__ADC0P10;
		ADC0CF = 
			(1 << ADC0CF_ADSC__SHIFT) 			| 
			ADC0CF_AD8BE__NORMAL 				| 	// ADC set to 10 bit
			ADC0CF_ADGN__GAIN_1 				|	// ADC gain set to 1
			ADC0CF_ADTM__TRACK_NORMAL;				// Immediate covert
		ADC0CN0 &=
			~ADC0CN0_ADCM__FMASK;
		ADC0CN0 |= 
			ADC0CN0_ADEN__ENABLED				|
			ADC0CN0_ADCM__ADBUSY;
	// Timer 0
		TCON_save = TCON;
		TCON &= 
			TCON_TR0__BMASK 					&	 
			TCON_TR1__BMASK;
		TH1 = (150 << TH1_TH1__SHIFT);
		TL1 = (150 << TL1_TL1__SHIFT);
		TCON = 
			TCON_save;
	// Timer setup
		CKCON = 
			CKCON_SCA__SYSCLK_DIV_12 			| 
			CKCON_T0M__PRESCALE 				| 
			CKCON_T3MH__EXTERNAL_CLOCK 			| 
			CKCON_T3ML__EXTERNAL_CLOCK			| 
			CKCON_T1M__SYSCLK;
		TMOD = 
			TMOD_T0M__MODE0 					| 
			TMOD_CT0__TIMER 					| 
			TMOD_GATE0__DISABLED				| 
			TMOD_T1M__MODE2 					| 
			TMOD_CT1__TIMER 					| 
			TMOD_GATE1__DISABLED;
		TCON |= 
			TCON_TR1__RUN ;
	// UART
		SCON0 |= 
			SCON0_REN__RECEIVE_ENABLED;
	// VREF
		REF0CN = 
			REF0CN_REFSL__VDD_PIN 				| 
			REF0CN_IREFLVL__1P65 				| 
			REF0CN_GNDSL__GND_PIN				| 
			REF0CN_TEMPE__TEMP_DISABLED;
	// RSTSRC
		RSTSRC = 
			RSTSRC_C0RSEF__NOT_SET 				| 
			RSTSRC_MCDRSF__SET 					| 
			RSTSRC_PORSF__SET					| 
			RSTSRC_SWRSF__NOT_SET;
	// Interrupt
		IE = 
			IE_EA__ENABLED 						| 
			IE_EX0__DISABLED 					| 
			IE_EX1__DISABLED 					| 
			IE_ESPI0__DISABLED					| 
			IE_ET0__DISABLED 					| 
			IE_ET1__ENABLED						| 	// Timer 1 enabled
			IE_ET2__ENABLED 					| 	// Timer 2 enabled
			IE_ES0__ENABLED;
		IP = 
			IP_PX0__LOW 						| 
			IP_PX1__LOW 						| 
			IP_PSPI0__LOW 						| 
			IP_PT0__LOW 						| 
			IP_PT1__LOW							|
			IP_PT2__HIGH 						| 	// Timer 2 highest priority
			IP_PS0__LOW;
	// PCA
		PCA0CN_CR =
			PCA0CN_CR__STOP;
		PCA0CPM0 = 
			PCA0CPM0_CAPN__DISABLED 			| 
			PCA0CPM0_ECCF__ENABLED 				| 
			PCA0CPM0_MAT__ENABLED				| 
			PCA0CPM0_CAPP__DISABLED 			| 
			PCA0CPM0_ECOM__ENABLED				| 
			PCA0CPM0_PWM__ENABLED 				| 
			PCA0CPM0_TOG__DISABLED;
		PCA0CPM1 = 
			PCA0CPM1_CAPN__DISABLED 			| 
			PCA0CPM1_ECCF__ENABLED 				|		 
			PCA0CPM1_MAT__ENABLED				| 
			PCA0CPM1_CAPP__DISABLED 			| 
			PCA0CPM1_ECOM__ENABLED				| 
			PCA0CPM1_PWM__ENABLED 				| 
			PCA0CPM1_TOG__DISABLED;
		PCA0MD = 
			PCA0MD_CIDL__NORMAL 				| 
			PCA0MD_ECF__OVF_INT_DISABLED 		| 
			PCA0MD_CPS__SYSCLK;		
		PCA0CN |= 
			PCA0CN_CR__RUN;
	// Timer 2
		TMR2CN |= TMR2CN_TR2__RUN;
	// End of peripheral setup
}

//-----------------------------------------------------------------------------
// END
//-----------------------------------------------------------------------------

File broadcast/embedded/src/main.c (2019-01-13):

//-----------------------------------------------------------------------------
// Project: Circus/broadcast
// File: 	main.c
// Brief:	Single main file containing all code
//-----------------------------------------------------------------------------

//-----------------------------------------------------------------------------
// Includes
//-----------------------------------------------------------------------------

#include "SI_C8051F850_Register_Enums.h"
#include "SI_C8051F850_Defs.h"

//-----------------------------------------------------------------------------
// Defines
//-----------------------------------------------------------------------------

#define SYSCLK      	24500000   		   // SYSCLK frequency in Hz
#define BAUDRATE     9600			      // Baud rate of UART in bps

SBIT(LEDR, SFR_P1, 2);                 		// P1.2 LED

//-----------------------------------------------------------------------------
// Prototypes
//-----------------------------------------------------------------------------
void setup(void);

//-----------------------------------------------------------------------------
// Global Variables
//-----------------------------------------------------------------------------

volatile U8 carrier_on;

//-----------------------------------------------------------------------------
// Main Routine
//-----------------------------------------------------------------------------

void main (void){
   // Init 
   U32 i;
   carrier_on  = 1;
   LEDR        = 0;
   // !Init

   // Setup
   
   // Disabled watchdogk
   WDTCN    = 0xDE;
   WDTCN    = 0xAD;
	
   // CPU clock
   CLKSEL   = CLKSEL_CLKSL__HFOSC | 
              CLKSEL_CLKDIV__SYSCLK_DIV_1;	 
  
   // Setup XBAR  
   P0MDOUT  = P0MDOUT_B4__PUSH_PULL;            
   P1MDOUT  = P1MDOUT_B1__PUSH_PULL|
              P1MDOUT_B2__PUSH_PULL; 
   P0SKIP   = 0xEF;                             // Skip all but UART pin
   P1SKIP   = 0xFD;	                           // Skip all but PWM pin
   XBR0     = XBR0_URT0E__ENABLED;              // Route out UART
   XBR1     = XBR1_PCA0ME__CEX0;                // Route out PCA0.CEX0 to P1.1
   XBR2     = XBR2_WEAKPUD__PULL_UPS_ENABLED | 
              XBR2_XBARE__ENABLED;					 
     
   // Start 38KHz clock
   PCA0CN   = PCA0CN_CR__STOP;
   PCA0CPH0 = 27;
   PCA0CPL0 = 0;
   PCA0MD   = PCA0MD_CPS__SYSCLK_DIV_12;		
   PCA0CPM0 = PCA0CPM0_ECOM__ENABLED  | 
			     PCA0CPM0_TOG__ENABLED   | 
              PCA0CPM0_MAT__ENABLED   | 
              PCA0CPM0_PWM__ENABLED   |
              PCA0CPM0_PWM16__16_BIT;
   PCA0CN   = PCA0CN_CR__RUN;  
            
   // Setup 1200 Baud UART and BAUD gen on timer 1
	CKCON    = CKCON_SCA__SYSCLK_DIV_48;
	TMOD     = TMOD_T1M__MODE2;
	TCON     = TCON_TR1__RUN; 
   TH1      = 0x2B;                             // Magic values from datasheet
	TL1      = 0x2B;

   // Setup pin interrupt
   TCON    |= TCON_IT0__EDGE;
   IT01CF   = IT01CF_IN1PL__ACTIVE_LOW |
              IT01CF_IN1SL__P0_3       |
              IT01CF_IN0PL__ACTIVE_HIGH |
              IT01CF_IN0SL__P0_3; 
   
   // Interrupts 
   IE       = IE_EA__ENABLED  |
              IE_EX0__ENABLED |
              IE_EX1__ENABLED; 
   // !Setup
 
   while(1){
      for(i=0;i<400000;i++);
      SBUF0 = 'A';
   }; 
} 

//-----------------------------------------------------------------------------
// Interrupt Routines
//-----------------------------------------------------------------------------

INTERRUPT (INT0_ISR, INT0_IRQn){				      // Attached to UART output	  
   IT01CF   |= IT01CF_IN0PL__ACTIVE_HIGH;
   PCA0CN   = PCA0CN_CR__STOP;
}

INTERRUPT (INT1_ISR, INT1_IRQn){				      // Attached to UART output	 
   IT01CF   |= IT01CF_IN0PL__ACTIVE_LOW;
   PCA0CN    = PCA0CN_CR__RUN;
}
//-----------------------------------------------------------------------------
// END
//-----------------------------------------------------------------------------

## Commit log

2018-06-24 copy over c files from Switcher
2018-06-26 Add datasheet, schs for ir and mcu
    [circus_agent.kicad_pcb, circus_agent.sch]
2018-06-26 added highside switch
    [circus_agent.sch]
2018-06-27 Added supercap and power rails
    [circus_agent.sch]
2018-06-27 Added h bridge and nmos
    [circus_agent.sch]
2018-06-28 Added BJT for highsides
    [circus_agent.sch]
2018-06-28 add battery measure and ID
    [circus_agent.sch]
2018-06-29 add pdfs and synbols for leds and prog
    [circus_agent.sch]
2018-06-30 added the pinout, LDO
    [circus_agent.sch]
2018-07-01 Duel drive with LEDs and ID. Added header
    [circus_agent.sch]
2018-07-04 designators and pass erc
    [circus_agent.sch]
2018-07-10 temp footprint and charge detection
    [circus_agent.sch]
2018-07-14 ADC and timer driven software pwm working on card
2018-07-14 Added IR footprint
2018-07-14 more footprints
2018-07-14 Motor, cap footprints and remove reverse fet
    [circus_agent.sch]
2018-07-14 updated power rails
    [circus_agent.kicad_pcb, circus_agent.sch]
2018-07-14 first stab at layout
    [circus_agent.kicad_pcb]
2018-07-15 First outline for PCB
    [circus_agent.kicad_pcb, circus_agent.sch]
2018-07-15 adjust outline
    [circus_agent.kicad_pcb]
2018-07-15 Added 3d model
    [circus_agent.step]
2018-07-18 Opt PCB layout and adjust drc
    [circus_agent.kicad_pcb]
2018-07-19 More layout opt and Rev A marking
    [circus_agent.kicad_pcb]
2018-07-20 final route opt
    [circus_agent.kicad_pcb]
2018-07-22 Generate gerbers
2018-07-23 flash script and TEST UART
2018-08-05 Added set and clear button to GUI
2018-08-07 Added timer for buffer
2018-08-09 add uart writer
2018-08-23 Fixes #3
    [20180823.csv]
2018-08-24 LED/opamp data sheets and started capture
    [circus_broadcast.kicad_pcb, circus_broadcast.sch]
2018-09-30 sw pwm working with motors
2018-10-01 Added LM317 to broadcast
    [circus_agent.kicad_pcb, circus_broadcast.sch]
2018-10-02 Added mcu circuit and format
    [circus_broadcast.sch]
2018-10-08 Added designators and values
    [circus_broadcast.sch]
2018-10-16 Added ADC, LEDS and passes erc
    [circus_broadcast.sch]
2018-10-18 Associate, footprint and start placement
    [circus_broadcast.kicad_pcb, circus_broadcast.sch]
2018-10-21 MOre lyaout
    [circus_broadcast.kicad_pcb]
2018-11-05 All all footprints and made 0.1 inch headers bigger
    [circus_broadcast.sch]
2018-11-07 First passing layout
    [circus_broadcast.kicad_pcb]
2018-11-08 tidy routing
    [circus_broadcast.kicad_pcb]
2018-11-09 Final layout
    [circus_broadcast.kicad_pcb]
2018-11-09 Remove copper text
    [circus_broadcast.kicad_pcb]
2018-11-09 Export gerbers
    [circus_broadcast.kicad_pcb]
2018-12-11 Order placed
    [20181211.csv]
2019-01-13 UART working over IR at 1200 baud
